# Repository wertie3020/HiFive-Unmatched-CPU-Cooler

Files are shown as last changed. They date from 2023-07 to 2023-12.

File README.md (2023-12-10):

# HiFive-Unmatched-CPU-Cooler
A HiFive Unmatched CPU cooler heat-sink.
This heat-sink wil be a 3d model that can be 3d printed at pcbway in Aluminium

## Benchmark

### Noctua NF-A4x10 FLX old heat-sink



- blowfish: 12.96
- cryptohash: 74.71
- fibonacci: 2.31 
- N-Queens: 16.20
- Zlib: 0.11
- FFT: 16.30
- Raytracing: 9.73
- tmp: 48

### Noctua NF-A4x10 FLX new heat-sink



- blowfish: 16.94
- cryptohash: 76.42
- fibonacci: 2.32 
- N-Queens: 16.12
- Zlib: 0.11
- FFT: 16.42
- Raytracing: 9.76
- tmp: 36

### Conclusion
the temperature has been lowered by 12 degrees. and we see a slight improvement in blowfish and ryptohash benchmarks

## Software
A list of all the software/website that is used to creat the heat-sink.
- FreeCAD
- PCBway https://www.pcbway.com/
- 

## Parts

### Ventilator
For the ventilator use the Noctua NF-A4x10 FLX, Premium Quiet Fan, 3-Pin (40x10mm, Brown)
https://www.amazon.com/Noctua-Cooling-Blades-Bearing-NF-A4x10/dp/B009NQLT0M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

### Heat-sink
1. first version

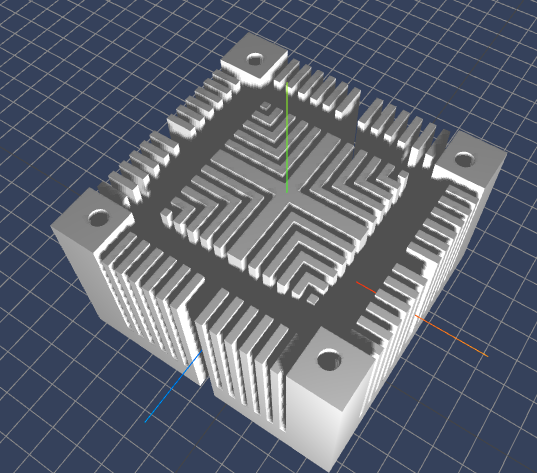
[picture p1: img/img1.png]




2. second version

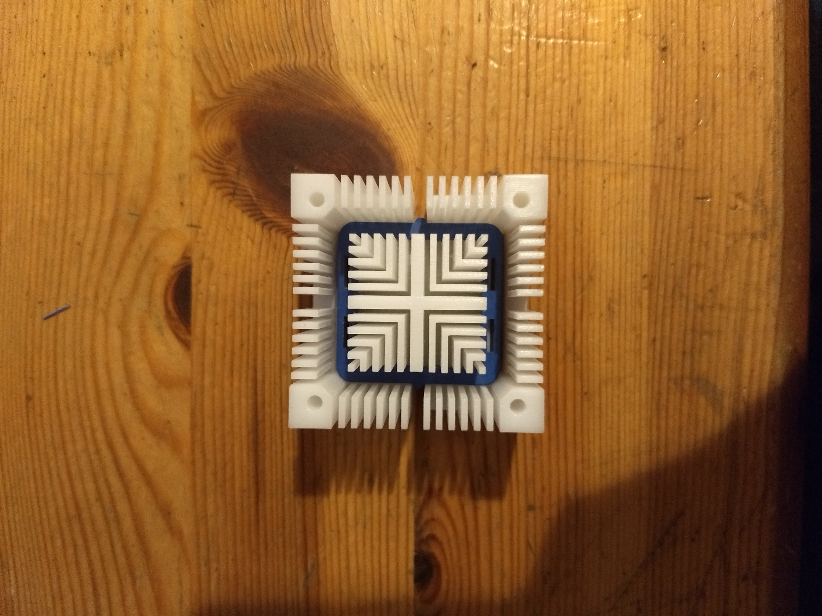
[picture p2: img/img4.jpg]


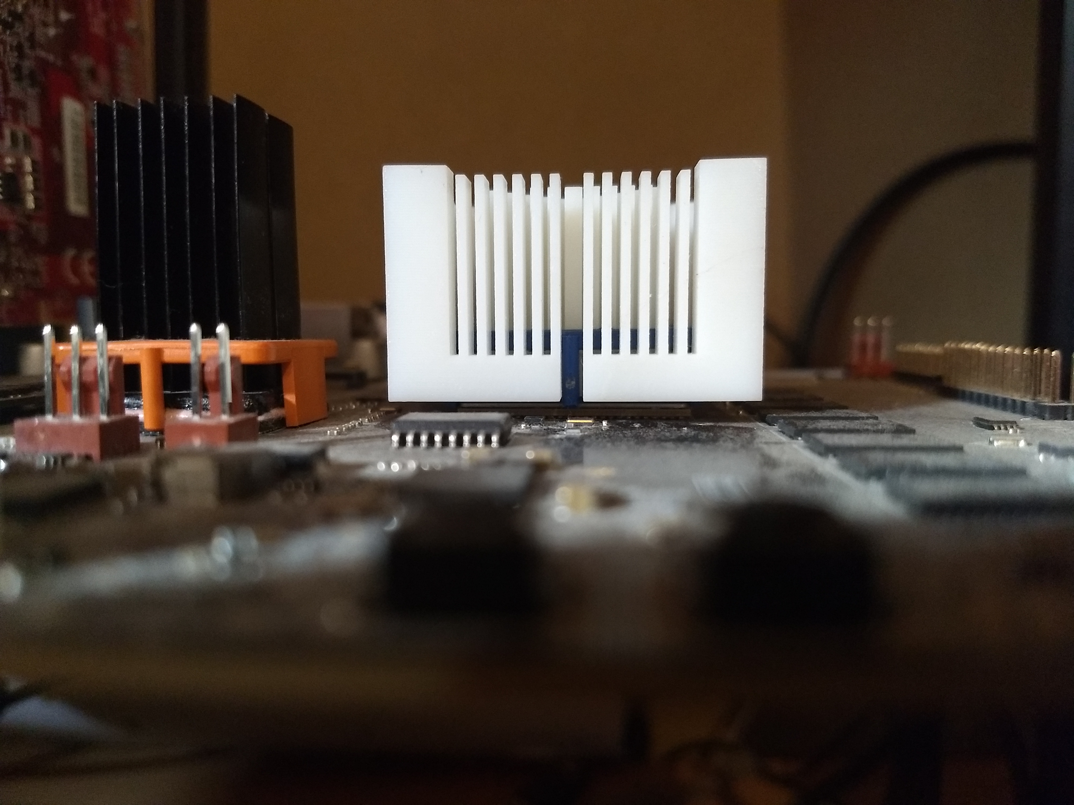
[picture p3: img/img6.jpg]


## Instructions
1. remove old heat-sink
2. modify the blue holder by removing the inner pieces
3. print the new heat-sink
4. order a fan like the Noctua NF-A4x10 FLX
5. make some M3 treads in the mounting hols for the fan
6. clean the cpu surface so there is no Thermal paste left
7. add new tThermal paste to the cpu
8. push the blue holder true the heat-sink
9. mount the heat-sink to the cpu 
10. screw in the fan with m3 screws

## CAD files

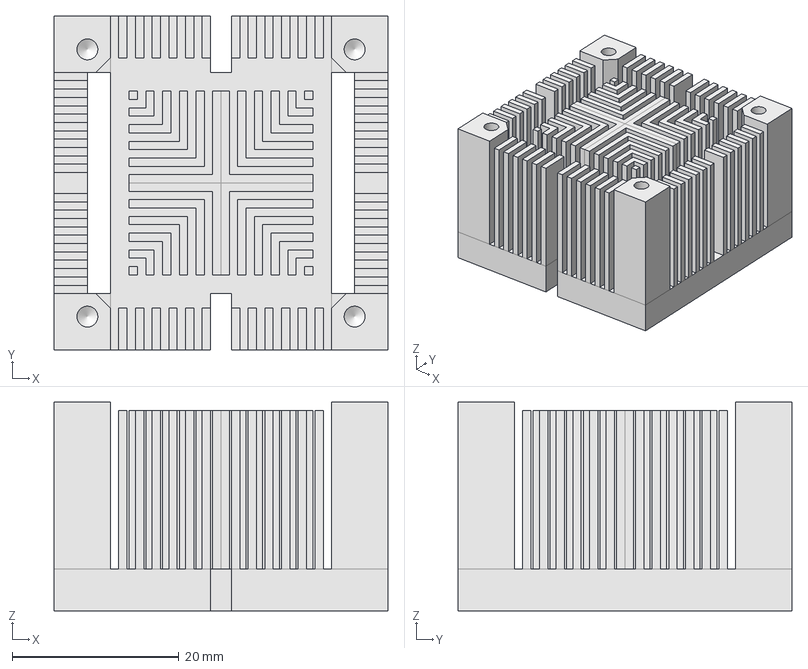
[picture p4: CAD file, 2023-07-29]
HiFiveUnmatchedHeatsink.FCStd
40.0 x 40.0 x 25.0 mm

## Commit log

2023-07-15 add freeCAD file
    [HiFiveUnmatchedHeatsink.FCStd]
2023-07-29 update heatsink to version 2
    [HiFiveUnmatchedHeatsink.FCStd]
